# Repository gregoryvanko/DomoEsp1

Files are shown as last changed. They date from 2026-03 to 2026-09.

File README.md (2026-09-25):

# DomoEsp1
Firmware ESP32 (PlatformIO / Arduino) qui lit 8 boutons + une temperature et publie leur état sur un broker MQTT, via la connexion WiFi gérée par la librairie `WifiAuto`.
La valeur d'une pin est envoyée sur le broker mqtt lors du changement d'état de cette pin.
La valeur de la température est envoyée sur le borker mqtt toutes les 60sec

## Fonctionnement général

1. Au démarrage, `WifiAuto` connecte l'ESP32 au WiFi puis au broker MQTT (portail de configuration si aucun identifiant n'est enregistré).
2. Une fois connecté au broker, l'ESP32 s'abonne au topic `CONFIG_MQTT_TOPIC_GET`.
3. Chaque changement d'état d'un bouton (après anti-rebond) est publié sur `CONFIG_MQTT_TOPIC_PIN` + numéro du bouton, avec la valeur `0` ou `1`.
4. Toutes les 60 secondes la valeur de la sonde de temperature est publiée sur `CONFIG_MQTT_TOPIC_TEMPERATURE`.
5. Une fois connecté au WiFi, l'ESP32 active la mise à jour du firmware par le réseau (OTA), accessible sous le nom `ESP-Garage.rix` (réservation DHCP de l'IP de l'ESP32 dans le routeur).

## Message MQTT
- L'ESP32 fait un subscribe sur le topic "Domo1/Get".
  - Si le payload = "All" alors il envoit le status de toutes les pin sur leur topic.
- L'ESP32 publie le statu d'une pin sur le topic "Domo1/PinX" (ou x est le numéro de la pin allant de 1 à 8). Le payload contient la statu de la pin
- L'ESP32 publie la temperature de la sonde DS18B20 sur le topic "Domo1/Temp1". Le payload contient la temperature en degré.

## Mise à jour du firmware par WiFi (OTA)
Voici la configuration PlatformIO, deux environnements : un pour l'USB, un pour l'OTA.

```ini
[env:esp32dev]
platform = espressif32
board = esp32dev
framework = arduino
monitor_speed = 115200
lib_deps =
	knolleary/PubSubClient@^2.8
	paulstoffregen/OneWire@^2.3.8
	milesburton/DallasTemperature@^4.0.6

[env:esp32dev_ota]
extends = env:esp32dev
upload_protocol = espota
upload_port = ESP-Garage.rix
upload_flags = --auth=<mot de passe OTA>
```

> Ne pas ajouter la librairie `jandrassy/ArduinoOTA` : elle est prévue pour d'autres cartes et peut entrer en conflit avec la version native de l'ESP32.

## Pinout ESP32
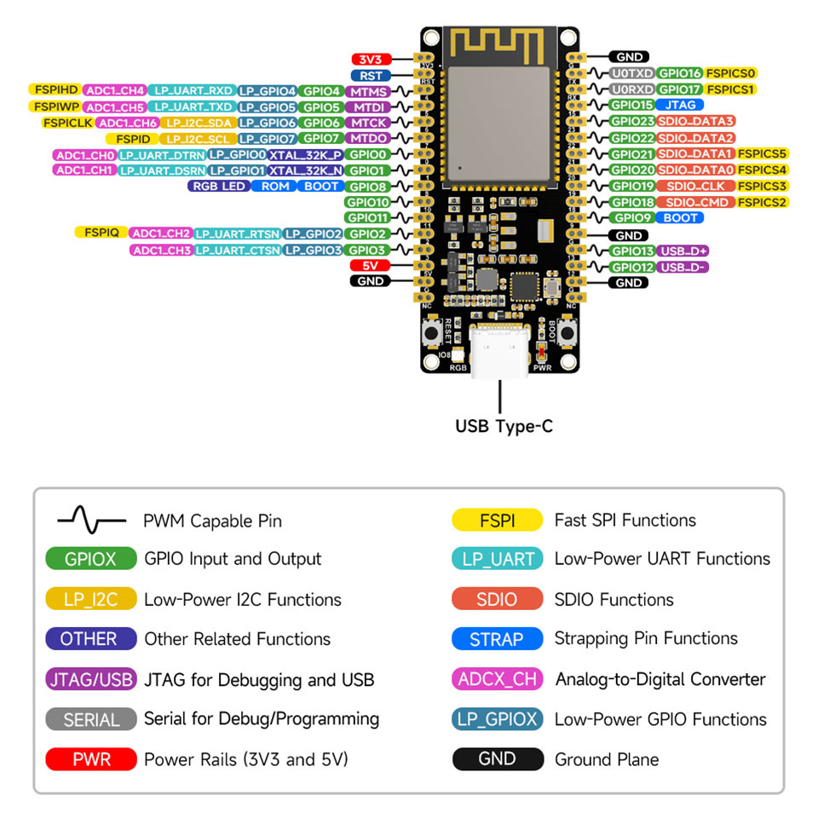
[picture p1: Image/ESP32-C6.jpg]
Alt ESP32


| GPIO | MQTT | source | status |
|:--- |:--- |:--- |:--- |
| GPIO13 | Pin1 | Porte garage (aimant) | 0 = porte fermée |
| GPIO14 | Pin2 | Porte Atelier | 1 = porte fermée |
| GPIO15 | Pin3 | Porte Fen SAM | 1 = porte fermée |
| GPIO17 | Pin4 | Porte Fen Cuisine | 1 = porte fermée |
| GPIO18 | Pin5 | Porte garage (alarme) | 1 = porte fermée |
| GPIO19 | Pin6 | Armé Absent | 1 = non armé |
| GPIO21 | Pin7 | Armé Nuit | 1 = non armé |
| GPIO22 | Pin8 | Porte Entree | 1 = porte fermée |
| GPIO23 | Temp1  | sonde DS18B20 | température deg |

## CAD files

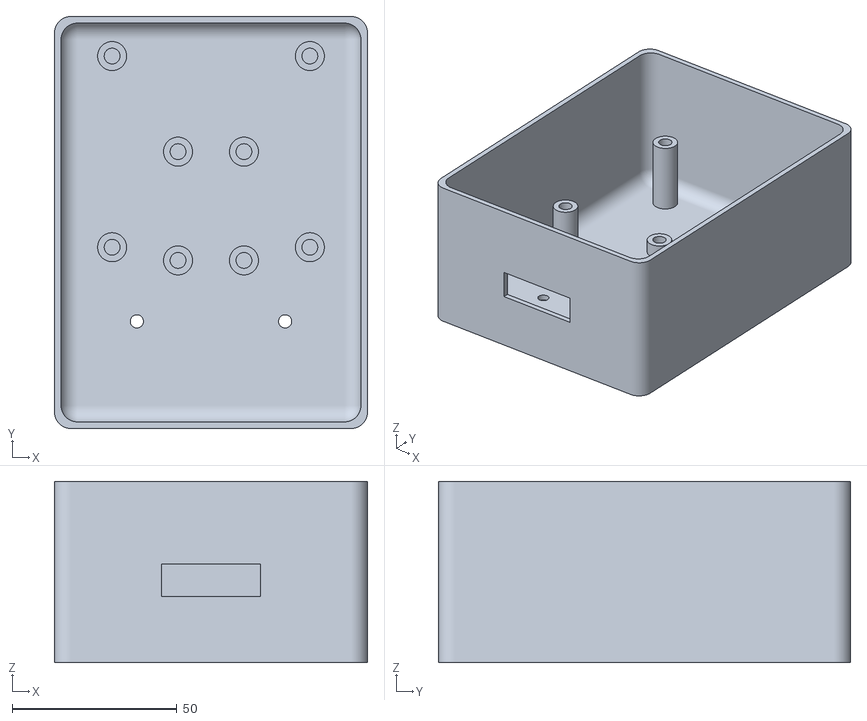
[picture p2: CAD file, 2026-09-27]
stl/Socle.stl
95.0 x 125.0 x 55.0

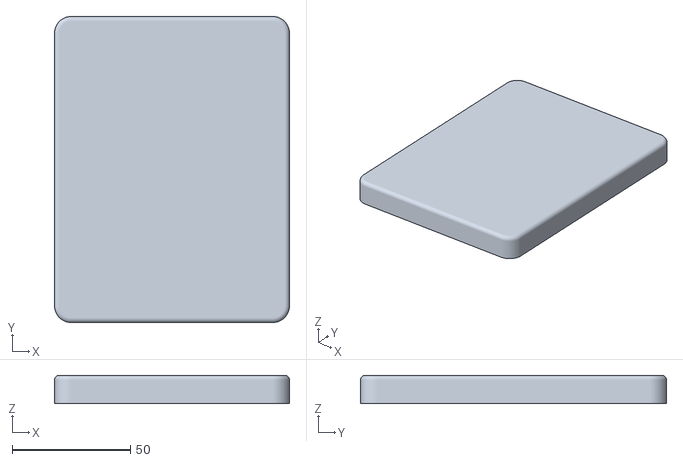
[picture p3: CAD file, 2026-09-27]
stl/Couvercle.stl
99.2 x 129.2 x 12.0

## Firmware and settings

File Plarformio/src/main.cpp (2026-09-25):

#include <Arduino.h>
#include "config.h"
#include "WifiAuto.h"
#include "Button.h"
#include "SensorTemperature.h"
#include <ArduinoOTA.h>

// Definition du wifi
WifiAuto wifi(CONFIG_PIN_BUTTON_BOOT, CONFIG_WIFI_ESP32SSID, CONFIG_MQTT_TOPIC_STATUS);

// Definition du capteur de temperature
SensorTemperature SensorTemperature1(CONFIG_PIN_TEMPERATURE);

// Definition des bouttons
Button boutons[] = {
  Button(CONFIG_PIN_BUTTON1, false, CONFIG_DEBOUNCE_MS),
  Button(CONFIG_PIN_BUTTON2, false, CONFIG_DEBOUNCE_MS),
  Button(CONFIG_PIN_BUTTON3, false, CONFIG_DEBOUNCE_MS),
  Button(CONFIG_PIN_BUTTON4, false, CONFIG_DEBOUNCE_MS),
  Button(CONFIG_PIN_BUTTON5, false, CONFIG_DEBOUNCE_MS),
  Button(CONFIG_PIN_BUTTON6, false, CONFIG_DEBOUNCE_MS),
  Button(CONFIG_PIN_BUTTON7, false, CONFIG_DEBOUNCE_MS),
  Button(CONFIG_PIN_BUTTON8, false, CONFIG_DEBOUNCE_MS),
};
constexpr size_t NB_BOUTONS = sizeof(boutons) / sizeof(boutons[0]);

// Action lors d'un chengement d'état se réalise sur un bouton
void ActionOnButtonChange(uint8_t PinNumber, bool pinvalue) {
  // Print pin value
  Serial.println("pin " + String(PinNumber) + " : " + String(pinvalue));

  // Send MQTT message
  wifi.mqttPublish(String(CONFIG_MQTT_TOPIC_PIN) + String(PinNumber), String(pinvalue));
}

// Publie l'état de tous les boutons
void SendAllStatus() {
  for (size_t i = 0; i < NB_BOUTONS; i++) {
    ActionOnButtonChange(i + 1, boutons[i].isHigh());
  }
}

// Definition du callback pour la reception des messages MQTT
void onMqttMessage(const String& topic, const String& payload) {
  Serial.println("Recu sur " + topic + " : " + payload);
  if (topic == CONFIG_MQTT_TOPIC_GET){
    if (payload == CONFIG_MQTT_PAYLOAD_ALL){
      // Send All buttons status
      SendAllStatus();
    } else {
      Serial.println("payload inconnu: " + payload);
    }
  } else {
    Serial.println("topic inconnu: " + topic);
  }
}

// Deniere mesure (ms)
uint32_t lastMesure = 0;

// Setup and loop
void setup() {
  // Start Serial
  Serial.begin(CONFIG_BAUDRATE);
  delay(1000);

  // Nom d'hote envoye au routeur par DHCP (doit etre appele avant wifi.begin())
  wifi.setHostname("ESP-Garage");

  // Definition du callback pour la reception des messages MQTT
  wifi.setMqttMessageCallback(onMqttMessage);

  // Definition du callback pour la connexion au broker MQTT
  wifi.onMqttConnected([]() {
    // Subscribe to the topic for receiving messages
    wifi.mqttSubscribe(CONFIG_MQTT_TOPIC_GET);
    // Send all buttons status at startup
    SendAllStatus();
  });

  // Demarre l'OTA une fois le wifi connecte (une seule fois, meme apres une reconnexion)
  wifi.onConnected([]() {
    static bool otaStarted = false;
    if (otaStarted) return;
    otaStarted = true;

    ArduinoOTA.setPassword("gregory");   // a definir dans config.h
    ArduinoOTA.onStart([]()  { Serial.println("OTA: debut"); });
    ArduinoOTA.onEnd([]()    { Serial.println("\nOTA: fin"); });
    ArduinoOTA.onProgress([](unsigned int progress, unsigned int total) {
      Serial.printf("OTA: %u%%\r", progress * 100 / total);
    });
    ArduinoOTA.onError([](ota_error_t error) {
      Serial.printf("OTA erreur %u\n", error);
    });
    ArduinoOTA.begin();
  });

  // Start WifiAuto
  wifi.begin();

  // Start buttons et definition des actions à réaliser lors d'un changement d'état
  for (size_t i = 0; i < NB_BOUTONS; i++) {
    uint8_t numero = i + 1;
    boutons[i].begin();
    boutons[i].onLow([numero]()  { ActionOnButtonChange(numero, 0); });
    boutons[i].onHigh([numero]() { ActionOnButtonChange(numero, 1); });
  }

  // Start temperature sensor
  SensorTemperature1.begin();
}

void loop() {
  // Update WifiAuto
  wifi.update();

  // Update ArduinoOTA
  ArduinoOTA.handle();

  // Update buttons
  for (Button& b : boutons) b.update();

  // Mesure toutes les CONFIG_MESURE_INTERVAL ms
  uint32_t now = millis();
  if (now - lastMesure >= CONFIG_MESURE_INTERVAL){
    // Update last mesure time
    lastMesure = now;
    // Read temperature
    float Temp = SensorTemperature1.read();
    // Send MQTT message
    wifi.mqttPublish(CONFIG_MQTT_TOPIC_TEMPERATURE, String(Temp));
  }
}

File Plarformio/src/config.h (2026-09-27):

#pragma once
// ── Setup ──────────────────────────────────────────────────────────────────────
constexpr int32_t CONFIG_BAUDRATE = 115200;
constexpr int32_t CONFIG_MESURE_INTERVAL = 60000;
constexpr uint8_t CONFIG_DEBOUNCE_MS= 50;
constexpr const char* CONFIG_WIFI_ESP32SSID = "ESP32-Garage";
// ── GPIO ──────────────────────────────────────────────────────────────────────-
constexpr uint8_t CONFIG_PIN_BUTTON_BOOT = 0;
constexpr uint8_t CONFIG_PIN_BUTTON1 = 13;
constexpr uint8_t CONFIG_PIN_BUTTON2 = 14;
constexpr uint8_t CONFIG_PIN_BUTTON3 = 16;
constexpr uint8_t CONFIG_PIN_BUTTON4 = 17;
constexpr uint8_t CONFIG_PIN_BUTTON5 = 18;
constexpr uint8_t CONFIG_PIN_BUTTON6 = 19;
constexpr uint8_t CONFIG_PIN_BUTTON7 = 21;
constexpr uint8_t CONFIG_PIN_BUTTON8 = 22;
constexpr uint8_t CONFIG_PIN_TEMPERATURE = 23;
// ── MQTT ──────────────────────────────────────────────────────────────────────-
constexpr const char* CONFIG_MQTT_TOPIC_STATUS = "Domogarage/status";
constexpr const char* CONFIG_MQTT_TOPIC_GET = "Domogarage/Get";
constexpr const char* CONFIG_MQTT_TOPIC_PIN = "Domogarage/Pin";
constexpr const char* CONFIG_MQTT_TOPIC_TEMPERATURE = "Domogarage/Temp1";
constexpr const char* CONFIG_MQTT_PAYLOAD_ALL = "All";

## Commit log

2026-02-08 Add initial Domo1 Arduino sketch with MQTT support
2026-02-22 Add card grid for pin and temperature values
2026-02-22 Refactor library includes and update configurations
    Updated library includes with version comments and adjusted GPIO input array declaration. Modified timer for sending temperature data and changed WebSocket event function name.
2026-02-22 Update temperature unit in WebSocket data handling
2026-03-01 Refactor pin analysis and debounce logic
    Refactor pin analysis to include button transition handling and update debounce delay.
2026-03-01 Update README with MQTT and ESP32 pinout
    Added MQTT message section and ESP32 pinout details.
2026-04-19 Modify GPIO inputs and implement LED blinking logic
    Updated GPIO input pins and added LED blinking functionality with timers. Adjusted color settings for LED based on connection status.
2026-04-26 Fix image path in README for ESP32 pinout
    Corrected image path for ESP32 pinout diagram.
2026-09-21 ajout des librairies wifi et mqtt
2026-09-23 ajout de la librairie mqtt
2026-09-24 ajout du code des bouttons et de la temperature
2026-09-25 mise en place de l'OTA
2026-09-27 New STL files
    [Couvercle.stl, DomoESP1-Boite.stl, DomoESP1-Couvercle.stl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]
